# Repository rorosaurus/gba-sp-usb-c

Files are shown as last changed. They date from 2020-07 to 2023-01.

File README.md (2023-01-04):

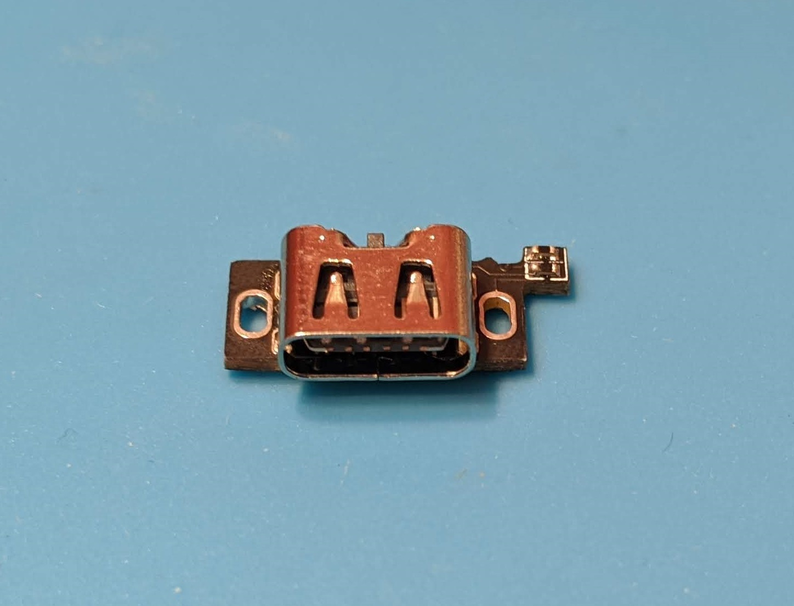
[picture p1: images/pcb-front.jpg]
PCB (https://www.tindie.com/products/20612/)


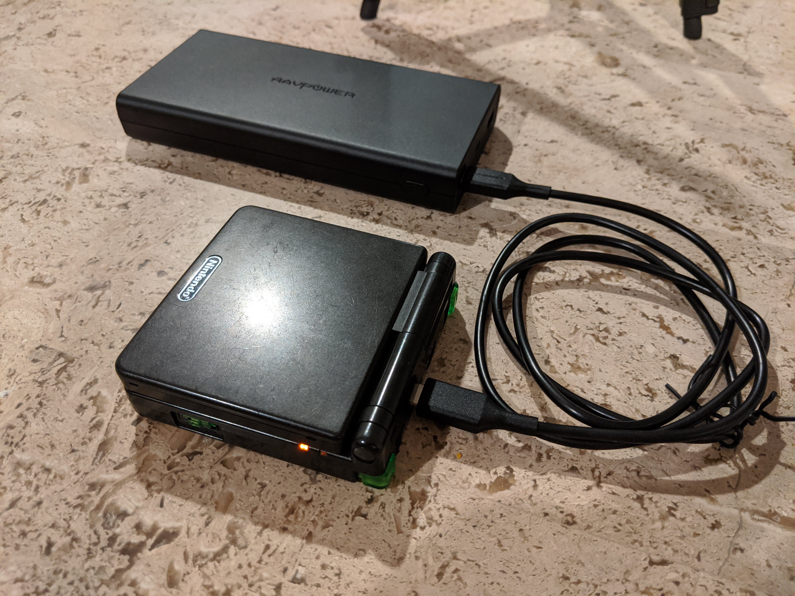
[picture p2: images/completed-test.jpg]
Final result (https://www.tindie.com/products/20612/)


# Where to Buy

* USA: [Buy on Amazon](https://smile.amazon.com/dp/B08L72TZWD) - [(Why Amazon?)](https://github.com/rorosaurus/gba-sp-usb-c/blob/master/why-sell-on-amazon.md)
* Any other Country: [Buy on Tindie](https://www.tindie.com/products/20612/) - (I will restock occasionally!)

## The truly universal USB-C dream is finally realized for your Game Boy Advance SP!

*(Also compatible with the original Nintendo DS!)*

Charge your Game Boy Advance SP with USB-C, using any USB-C cable and charger! If it fits, it'll charge! Finally you can stop carrying around that extra proprietary cable!

My design is based off [this existing PCB](https://oshpark.com/shared_projects/I6UOH6gb) that only works with ````USB-A -> USB-C```` cables. In my opinion, if you're gonna future-proof your Game Boy, you shouldn't remain reliant on Type-A!

My PCB works with ````USB-C <-> USB-C```` cables as well, so you can use ANY USB-C cable/charger to charge it! I've also verified it works with ````USB-A -> USB-C```` cables, Quick Charge, and USB-PD! That means if your charger or USB battery pack offers 5V/9V/12V/etc., it will recognize the Game Boy can only accept 5V and charge accordingly.

This product was featured on the [Tindie Blog](https://blog.tindie.com/2020/07/game-boy-advance-sp-usb-c-charging-port/)!

# Options

To reduce confusion and simplify filling orders, I've consolidated the options into just one offering which satisfies 70% of orders. I go into [a bit more detail here.](https://github.com/rorosaurus/gba-sp-usb-c/blob/master/why-sell-on-amazon.md)

I will assemble the components for you before shipping. You only have to desolder the existing charging port, then solder 3 points to attach to your Game Boy!

I will include a small 3D printed part to fill in the gap in the case created by the smaller USB-C port. It will friction-fit snugly, or you can use glue/epoxy to keep it in place. Some post-processing (sanding) might be necessary for the cleanest look.

# Compatibility

This design works for the AGS-001 and AGS-101.

This design is compatible with [3.5mm headphone jack mods](https://github.com/rorosaurus/gba-sp-headphone-jack)! That means my PCB will not block the other pins you need from the default charging port pads on the Game Boy's motherboard.

It also works on the original (fat) Nintendo DS, NTR-001. Now your Phat GBA Macro can use USB-C as well!

# Charge Speed

This console's original charger (AGS-002) outputs up to 320mA at 5.2V. According to the USB-C spec, this mod will allow charging at up to 500mA at 5V. This mod will not result in any charging slowdown compared to the original charger.

# Disclaimer

Modify your console at your own risk! This product is provided "as is", with no warranty - express or implied. That said, if you have any issues or questions, don't hesitate to reach out!

# Installation

Instructions for assembly/installation can be found in [INSTALLATION.md](https://github.com/rorosaurus/gba-sp-usb-c/blob/master/INSTALLATION.md)

# 3D Printed Spacer

The 3D print-able file to fill in the case gap is [on Thingiverse](https://www.thingiverse.com/thing:4123563).

# License
If you have improvements, please modify these design files and share any improvements openly/freely with the community (via a pull request or another public repository)!

You are not permitted to profit off of this design or use it in any commercial venture.

[Full license information.](https://github.com/rorosaurus/gba-sp-usb-c/blob/master/LICENSE.md)

# Thanks
Thank you to [makho](https://www.youtube.com/channel/UC5FYpo9lFqK1Y7wqjPuANFw) and [BlindEye/Hidarite](https://www.tindie.com/stores/hidarite/) for the original PCB inspiration, installation video, and STL file!

# Other Gameboy Mods

[Mods - Game Boy Subreddit Wiki](https://www.reddit.com/r/GameBoy/wiki/mods)

## My Other Gameboy Mods

* [USB-C Mod for Gameboy Advance SP (and original Nintendo DS)](https://github.com/rorosaurus/gba-sp-usb-c/)
* [USB-C Mod for Nintendo DS Lite](https://github.com/rorosaurus/nds-lite-usb-c/)
* [USB-C Mod for Nintendo 3DS XL](https://github.com/rorosaurus/3ds-xl-usb-c/)
* [List of headphone jack mods for the Gameboy Advance SP](https://github.com/rorosaurus/gba-sp-headphone-jack/)

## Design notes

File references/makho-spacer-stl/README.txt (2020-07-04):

AGS USB Type C Mod Bezel by makho on Thingiverse: https://www.thingiverse.com/thing:4123563

Summary
This file was created by BlindEye but it needed some tweaks to fit without having to mod it once printed. I made those tweaks.

I'm rehosting without his permission but since his store is abandoned and he does not reply to PMs, I don't really know what else to do. I'm sure it's fine.

Here are the PCBs that BlindEye made for this mod:
https://oshpark.com/shared_projects/I6UOH6gb

And these are the USB C ports that are needed:
https://www.aliexpress.com/item/32885941456.html

Here is the install and a bit more info about the mod:
https://www.youtube.com/watch?v=gBLHvdre-Xg

tl;dw, this is a mod for replacing the original, proprietary port with a USB Type C port for charging only. This mod will NOT allow for charging on a USB Type C host device and will ONLY work with a Type A -> Type C cable. Type C -> Type C will not work. I'm (eventually) going to redesigned the adapter to fix that but for now this is BlindEye's version.

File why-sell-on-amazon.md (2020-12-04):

# The quick explanation

## How selling on Amazon benefits you, the buyer
* The same order is $1.30 USD cheaper on the Amazon listing. (After factoring in your local tax rate, it's probably at or near the Tindie price.)
* Amazon will ship your order promptly. Previously, when manually shipping myself, I would wait several days to group together shipments.
* Free one or two day shipping! Previously, the shipping I offered was 3-7 days.
* Don't need a Tindie account. It seems like everyone already uses Amazon.

## How selling on Amazon benefits me, the seller
* I don't have to manually pack and ship each order!
* (That also means I can't make packing mistakes anymore! 😅)
* ... and that's it.
* Amazon takes a huge cut of each sale, so I estimate I'll make ~50% less on each sale.

# More detail

## Why are you selling on Amazon now?

Long story short, I'm spending more time than I'd prefer to right now, manually filling and shipping orders from Tindie. I love enabling people to revive and enjoy old electronics, so I've been looking for a way to reduce the daily/weekly effort I must invest to continue delivering these mods to you.

Using Amazon, I should be able to ship them a big box of the mods, then they will handle all the legwork of each shipment. So I can reduce my effort to just prepping that big box once a month or whenever.

I'm pretty satisfied with the solution I've arrived at, I think. According to my back-of-the-napkin math, customers will save about $1.30 USD compared to the same order on Tindie, and Amazon will ship much faster than I could. I will make less money per sale compared to Tindie, but profiting off this was never my goal in the first place so that's fine.

## Reducing options

One way I can simplify my time investment is by reducing the different options available. I previously offered unassembled/assembled options, with or without the 3D printed bezel part. The overwhelming majority (70%+) of orders were for the assembled board, with the 3D printed part. So to consolidate and simplify my packaging I've opted to only offer that from now on.

If you would still prefer to order unassembled board without the 3D printed part, you can find the PCB design files under `/gerber/`, which includes the BOM for you to order any parts you don't have on hand. You can use these to place your own order with a PCB manufacturer.

## International Orders

I'm still trying to figure out how to sell to other countries through Amazon. For now, as a backup, I will aim to **occasionally restock my Tindie store** so that I can fulfill several international orders at once (much easier than one-at-a-time). I'll remove the US domestic shipping option from this product on Tindie, so US-based customers can only purchase through Amazon.

So if you want this shipped outside the USA, and Tindie is out of stock, join the waitlist! You'll get an email notification when I restock!

# Thanks

I never expected so many people would want this mod! I'm grateful for your support and trust, and I sincerely hope my mods serve you well. Keep your eye out (hopefully next month or so!) for when I finalize and start selling the NDS-lite and 3DS-XL USB-C mods!

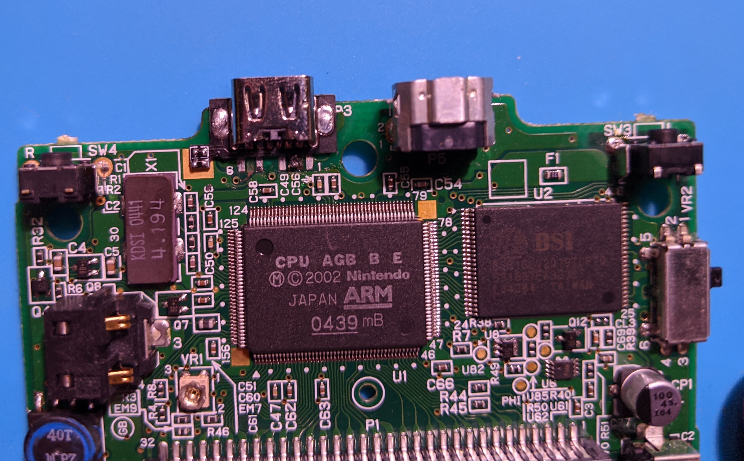
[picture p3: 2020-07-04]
images/motherboard-front.jpg

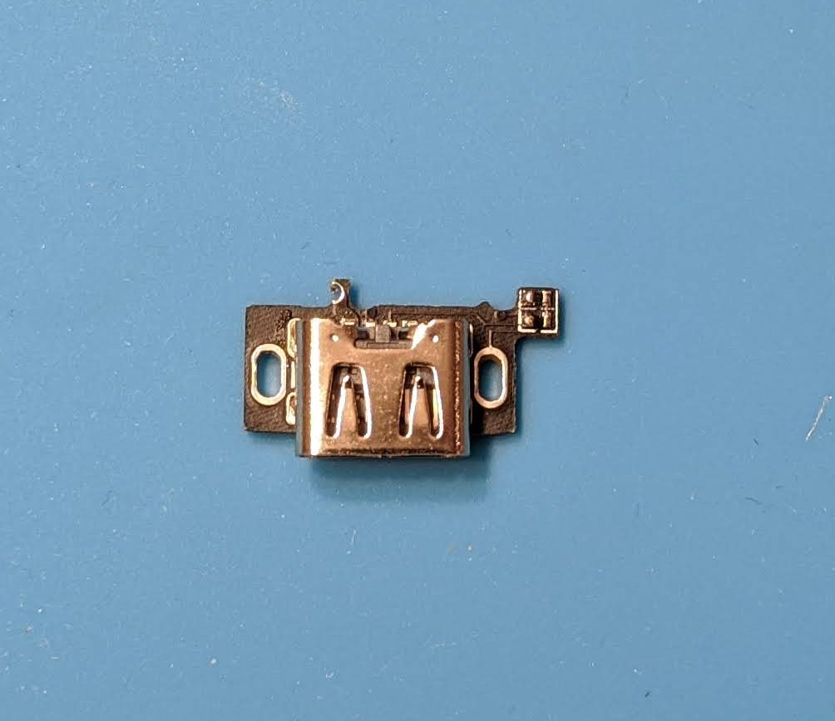
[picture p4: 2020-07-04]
images/pcb-top-down.jpg

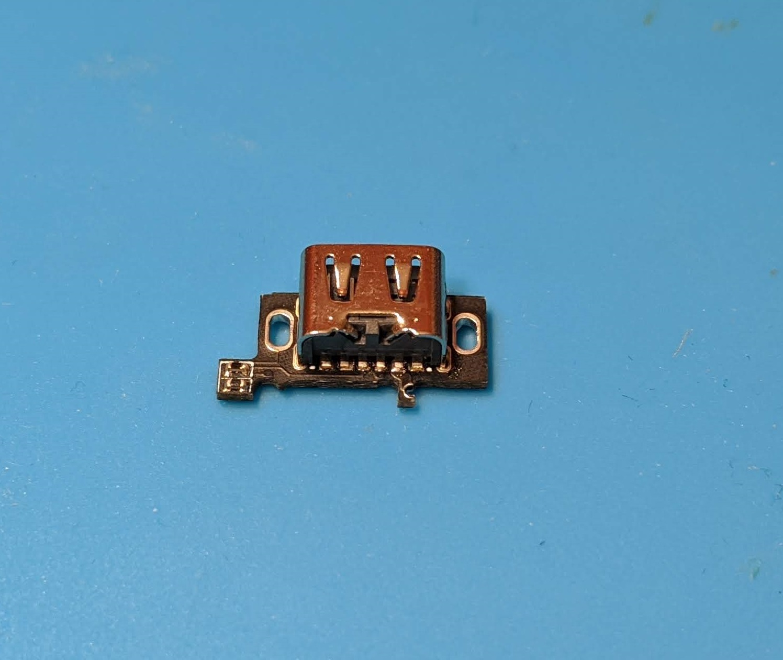
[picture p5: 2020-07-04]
images/pcb-back.jpg

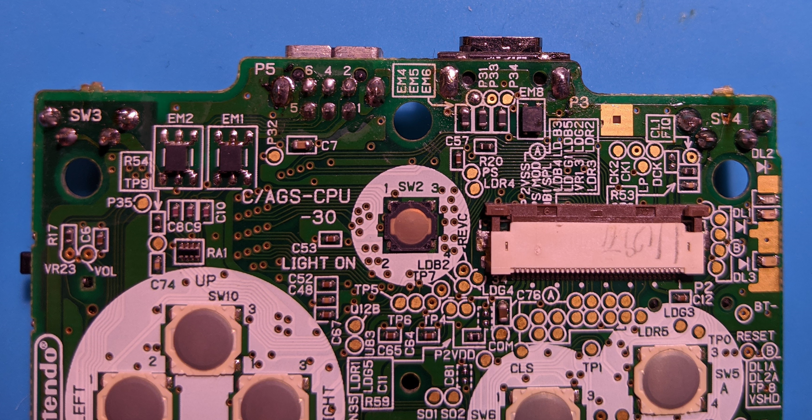
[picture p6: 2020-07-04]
images/motherboard-back.jpg

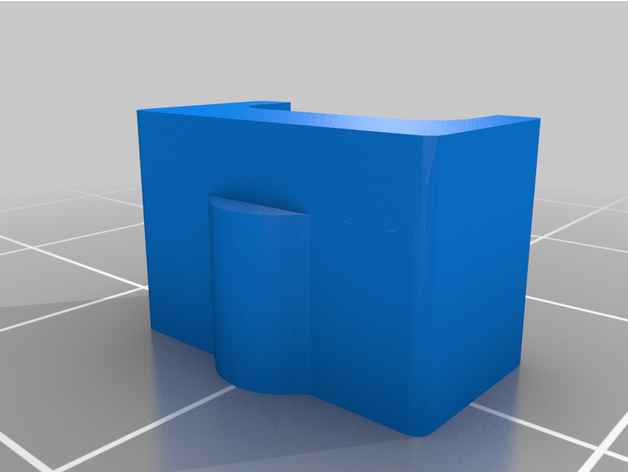
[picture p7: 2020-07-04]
references/makho-spacer-stl/images/AGS_C_Spacer.png

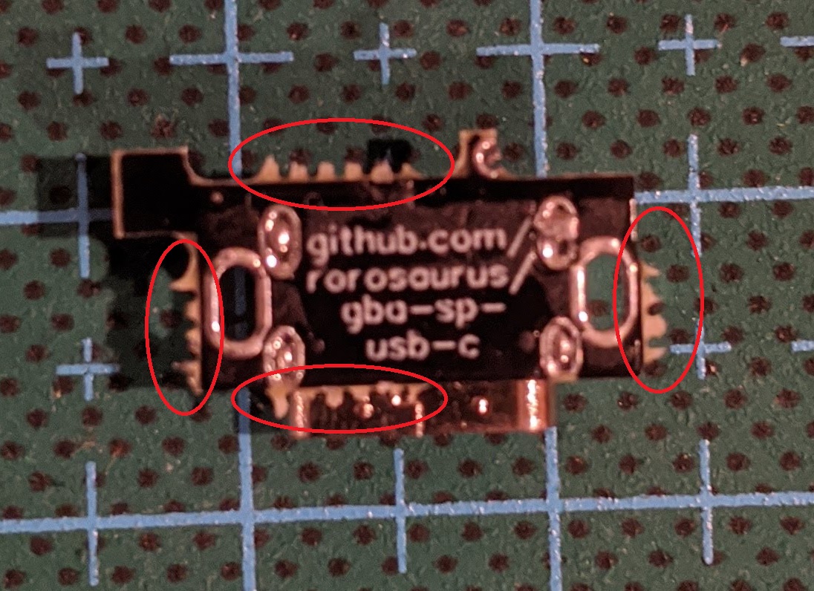
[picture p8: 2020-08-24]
images/breakaway-perforations.jpg

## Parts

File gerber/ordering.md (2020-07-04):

# Ordering PCB from my Tindie store
The PCB is [available to order on my Tindie store](https://www.tindie.com/products/20612/).

# Fabricating the PCB yourself
Order PCB with 0.8mm thickness!
USB-C port used: https://www.aliexpress.com/item/32885941456.html
5.1K resistors used: https://www.aliexpress.com/item/32864744837.html

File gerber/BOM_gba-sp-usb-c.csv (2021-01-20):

ID | Name | Designator | Footprint | Quantity | Manufacturer Part | Manufacturer | Supplier | Supplier Part
1 | 5.1K | R1,R2 | R0402 | 2 | RMC04025.1K5%N | Tyohm | LCSC | C325524
2 | TYPE-C-31-M-16 | USB1 | TYPE-C-SMD_TYPE-C-31-M-16 | 1 | TYPE-C-31-M-16 | Korean Hroparts Elec | LCSC | C283541

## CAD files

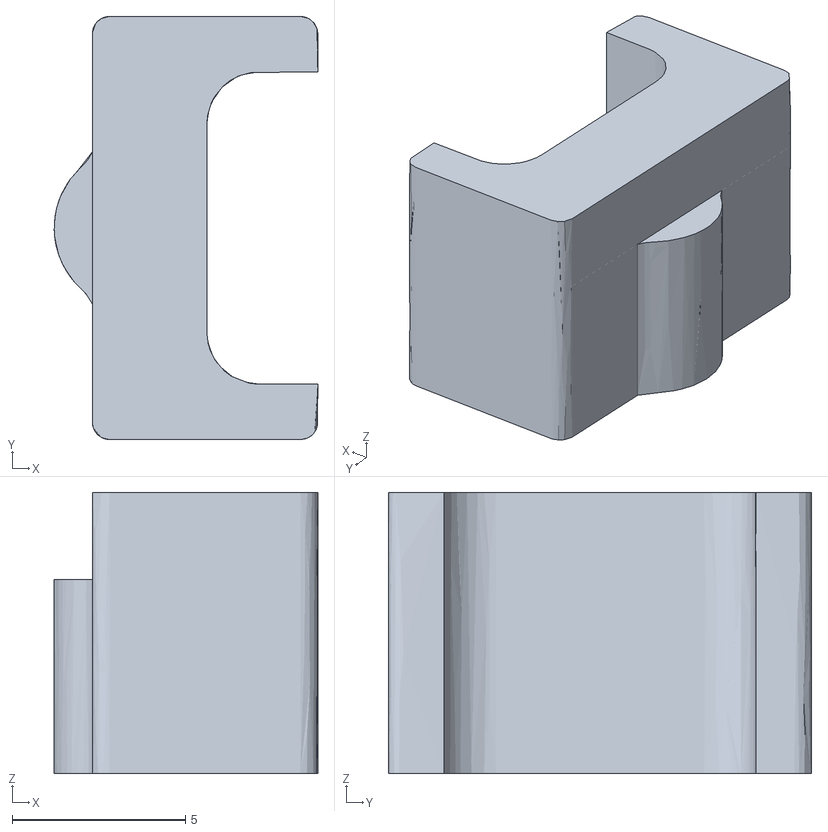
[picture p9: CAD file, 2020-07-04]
references/makho-spacer-stl/files/AGS_C_Spacer.stl
7.60 x 12.2 x 8.10

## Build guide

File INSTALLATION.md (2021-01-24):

# Prep

Your PCB might arrive with some [slight perforations, from the breakaway panelization design](https://github.com/rorosaurus/gba-sp-usb-c/blob/master/images/breakaway-perforations.jpg) during PCB manufacturing. These can be left alone, or optionally filed/sanded away. You probably want to file the top side flat, if you also intend to perform a 3.5mm headphone jack mod.

The half-circle pad(s) behind the USB-C connector might have some debris across it. You can safely clear that away with a toothpick or similar - that will make it easier to solder to later.

# Test before you install!

I test every board before shipping, but you should be certain it still works before you install it! Plug it in to a ````Type-C <-> Type-C```` cable and USB-C power source. **Do not perform this test with a ````Type-A -> Type-C```` cable - that cable won't verify the board works for full USB-C!** Use a multimeter to measure the voltage across any of the grounded holes and the +5V half-circle in the back. Ensure it reads ~5V. Flip your USB-C cable the other way around and verify it still reads 5V! Alternatively, if you have a USB-C multimeter [like this](https://smile.amazon.com/gp/product/B07X3HST7V/) you can simply plug into that and read the display.

# Installation Video

I highly recommend you watch [makho's video](https://www.youtube.com/watch?v=gBLHvdre-Xg) of installing a similar version of this PCB! This is an *awesome* overview that will be very helpful to reference. The below instructions simply outline what he does in the video.

# Instructions

1. Carefully desolder and remove existing charging port. Use a solder sucker and solder wick. Take your time and take great care to not get impatient and rip up any pads!
2. Fill in the standoffs on both PCB's (Game Boy and my PCB) with solder.
3. Ensure bottom of USB-C PCB is flat, as well as the top of the Game Boy motherboard. You can use flush cutters and solder wick to help you with this. You might need to gently and carefuly sand the bottom through-hole connections for the USB-C port to ensure they are fully flat.
4. Align the USB-C PCB so that the standoffs are directly above the Game Boy's and solder one joint.
5. Reheat the joint and realign as necessary to ensure the standoffs are aligned properly, and the 5V power line aligns well with the pad it will connect to.
6. Solder the remaining standoff to lock the USB-C PCB in place. Test the strength of this connection and reinforce if necessary. Remember it needs to support the stress of plugging in and pulling out many times!
7. Solder the 5V half circle pad to the 5V pad on the Game Boy motherbaord.
8. Plug in USB-C cable to test! Hooray!

# Troubleshooting

### Did you test the board before installing?

See above instructions! It's critical that you test this to ensure it was not damaged during shipping!

### Try with a different cable and/or charger

This mod should work with all combinations of cables and chargers, but try a different one to help diagnose the problem by eliminating variables.

### Flip the USB-C cable to the other orientation

If it works only in one orientation, then check the two small resistors. Ensure they are oriented properly and soldered to their pads. Reheat the solder joints with your iron and confirm continuity with your multimeter.

If it still only works in one orientation, sadly one of the six USB-C port pins has a bad connection to my PCB (damaged in shipping, most likely).

You can reflow these pins with your soldering iron, adding solder if needed. If you apply too much solder and the pins get bridged, you can use solder wick or a solder sucker to remove some.

### Did you accidentally lift up some of the original charging port's pads?

You can test with your multimeter that you have continuity from the USB-C port to the expected destination. You'll have to follow the traces or look up where they lead. You can often rewire directly to the destination if you've messed up the original charging port's pad.

### You heard a "click" or your console is no longer powering on

You might have just blown a fuse. Check F1 (or similar) for continuity and replace the part if necessary (replacement part list in the [Game Boy Discord](https://discord.gg/gameboy)). After searching for and fixing the short that caused the fuse to blow, of course!

### Still stuck?

If you're still stuck, the friendly folks in #modding on the [Game Boy Discord](https://discord.gg/gameboy) might be able to help you. Make sure you are patient and respectful - and clearly describe the problem and what you have tried to solve it so far.

I'm always available through Amazon/Tindie as well!

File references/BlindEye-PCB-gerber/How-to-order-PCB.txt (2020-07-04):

How to Order PCB

Please refer to:
https://docs.easyeda.com/en/PCB/Order-PCB

Order in 0.8mm

BlindEye’s AGS -> USB Type C adapter board. Requires these USB Type C ports: https://www.aliexpress.com/item/32885941456.html

Can also use this STL to 3D print a spacer (I finally fixed the spacing): https://cdn.discordapp.com/attachments/332487777986019337/670008168226619424/AGS_C_Spacer.stl

Or you can get it from my thingiverse: https://www.thingiverse.com/thing:4123563

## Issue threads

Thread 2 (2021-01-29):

3d part files

stuij, 2021-01-29:
Hey there,

Thanks for getting usb c <> usb c working. That's awesome. Maybe I want too much, but I was wondering if you could also put up the model for the bit to fill up the charging port hole. I'm not sure if i'm happy with black, and it'd be nice to have an excuse to fire up the 3d printer.

Thanks!

rorosaurus, 2021-01-29:
That file is in this repo, it's just a backup of mahko's original upload on Thingiverse: https://github.com/rorosaurus/gba-sp-usb-c/tree/master/references/makho-spacer-stl 🙂

Closed 2021-01-29.

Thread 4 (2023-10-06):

USB-C Mods design

B0jack91, 2023-10-06:
Hello @rorosaurus,

I was wondering if somehow it was possible to get the files for the pcb boards you designed for gba sp and nds lite. Im starting to learn more about modding and soldering these consoles and found your github and really interesting content you wrote. But noticed you stopped selling those USB-C ports (my assumption) so I was wondering if it was possible for you to consider publishing the PCB designs so others could keep working on modding using your mod instead of makho one, as basically yours seem to be an improved version of his.

Apologies if I bother you, not my intention, I am just trying to educate myself and was considering either buying your mod usb-c port, or if not available (as it looks) print it over sites as OSH Park.

Thank you so much for your time.
Best regards,

ABaumher, 2024-05-04:
may be somewhat late here but those files are shared in this repo. I'm in the process of doing this myself, and need this version as i indend to do this alongside a 3.5mm audio mod, which makes any other options available less ideal. That said, i have zero experience in generating PCBs, so take this with a grain of salt, i can't guarentee i will succeed, YMMV, etc.

It appears these were designed in easaeda, which is a tool for generating PCBs. The files were exported to a Gerber file, which is a zip folder containing various files needed to manufacture the PCB. PCB manufacturers can take this zip and generate a PCB for you.
The Gerber zip for this repo is at https://github.com/rorosaurus/gba-sp-usb-c/blob/master/gerber/gerber-gba-sp-usb-c-pcb.zip
I was able to dowload the zip from above, then upload it at the manufacturing site jlcpcb.com. I have heard good things about PCBWay as well, but their webpage is not as intuitive, and since i have less than zero experience in this, the simpler site won out ¯\_(ツ)_/¯
Their minimum quantity is 5, and it cost me $2USD (plus shipping).
From there, it also requires a transistor and the USB C port, which are listed in the gerber/ordering.md file. I've linked the two below for ease of access.
USB-C port used: https://www.aliexpress.com/item/32885941456.html
5.1K resistors used: https://www.aliexpress.com/item/32864744837.html
I'm expecting that i'll need to solder all of that together myself; if i can find a youtube video demonstrating this process, i will link it.

ABaumher, 2024-05-04:
Alternatively, the design available from Robot Retro, on https://handheldlegend.com/products/game-boy-advance-sp-usb-c-pcb-robot-retro is... eerily similar. Not sure that's in the spirit of the CC non-commercial license here, (the board layout is virtually identical, they just us different connection paths), but it means that it probably works just as well as this design. A question on the site states it does support 5V testing, though they don't make personal guarentees like the statements here, so take that as you will.

Closed 2024-05-08.

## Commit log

2020-08-08 clarify assembled
2021-01-20 remove unused parts from BOM
    [BOM_gba-sp-usb-c.csv]
2021-01-28 add charging speed information
2021-01-29 add direct link to 3d printer file
